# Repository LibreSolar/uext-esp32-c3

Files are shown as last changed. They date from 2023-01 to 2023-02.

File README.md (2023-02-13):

# WiFi/Bluetooth communication board based on ESP32-C3 for UEXT connector

 First boards tested, some issues might still be open.

Schematic: [PDF file](build/uext-esp32-c3.pdf)

Bill of Materials: [CSV file](build/uext-esp32-c3_bom.csv) or [interactive HTML BOM](https://libre.solar/uext-esp32-c3/build/uext-esp32-c3_ibom.html)

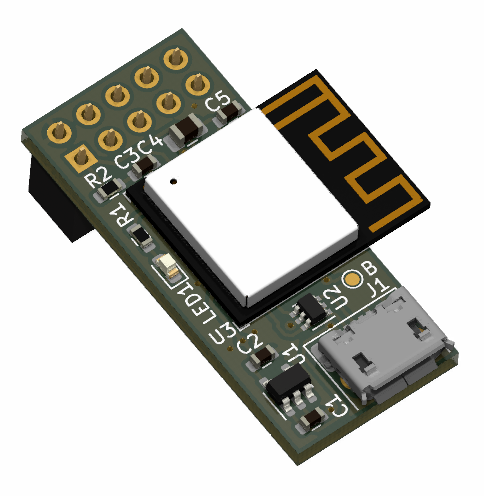
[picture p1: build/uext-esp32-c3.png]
UEXT ESP32 Module


## Features

- UEXT connector to communicate with host MCU via UART
- Flashing via built-in USB port
- Internal power supply for firmware upgrades

## Firmware

This board can be programmed with [Zephyr RTOS](https://docs.zephyrproject.org/latest/) or [ESP-IDF](https://docs.espressif.com/projects/esp-idf/en/latest/esp32c3/get-started/index.html).

## License

The hardware is licensed under the [CERN Open Hardware Licence Version 2 - Weakly Reciprocal](LICENCE).

Documentation is licensed under the [Creative Commons Attribution-ShareAlike 4.0 International (CC BY-SA 4.0) License](https://creativecommons.org/licenses/by-sa/4.0/).

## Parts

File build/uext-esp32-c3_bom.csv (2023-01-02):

Component | References | Value | Footprint | Description | Quantity Per PCB | Manufacturer | PartNumber | Remarks | DNM
1 | C5 | 100nF | C_0603_1608 |  | 1 | any |  | 50V, X7R
2 | C3 | 1uF | C_0603_1608 |  | 1 | any |  | 10V, X5R
3 | C1 C2 | 2.2u | C_0603_1608 |  | 2 | any |  | 10V, X5R
4 | C4 | 10uF | C_0805_2012 |  | 1 | any |  | 10V, X5R
5 | J2 | UEXT | PinSocket_2x05_P2.54mm_Vertical | Olimex UEXT connector (2x5 box header) | 1 | any
6 | J1 | USB_B_Micro | USB_Micro-B_10103594-0001LF | USB Micro Type B connector | 1 | Amphenol FCI | 10103594-0001LF
7 | LED1 | LED | LED_0603_1608Metric | Light emitting diode | 1 | any | red
8 | R1 | 1k | R_0603_1608 | Resistor | 1 | any
9 | R2 | 10k | R_0603_1608 | Resistor | 1 | any
10 | U1 | AP2210-3.3 | SOT-23-5 | 300mA low dropout linear regulator, shutdown pin, 1.5V fixed positive output, SOT-23-5 package | 1 | Diodes Inc. | AP2210K-3.3TRG1 | Alternative: MIC5225
11 | U3 | ESP32-C3-MINI-1 | ESP32-C3-MINI-1 | ESP32-C3-MINI-1 is a general-purpose Wi-Fi and Bluetooth LE module. This module features a rich set of peripherals and a small size, which makes it an ideal choice for smart home, industrial automation, health care, consumer electronics, etc | 1 | Espressif | ESP32-C3-MINI-1-N4
12 | U2 | NUP4202 | SOT-363_SC-70-6 | Transient voltage suppressor designed to protect high speed data lines from ESD, EFT, and lightning | 1 | On Semi | NUP4202W1T2G | Alternatives: Würth 82400274, Diodes D1213A-04S | Würth 82400274

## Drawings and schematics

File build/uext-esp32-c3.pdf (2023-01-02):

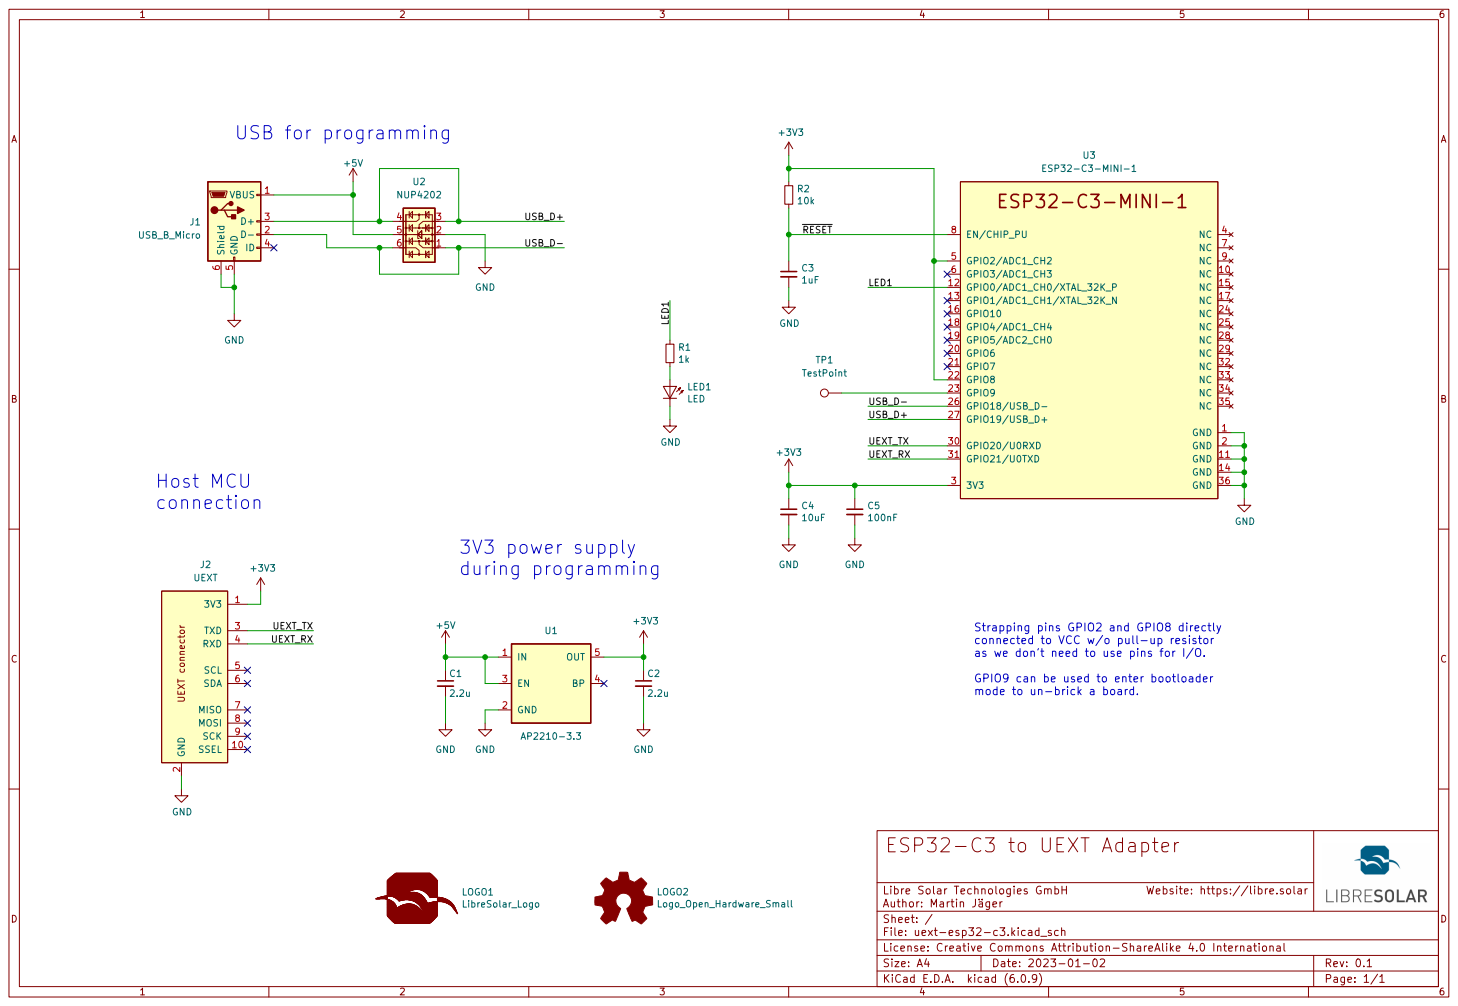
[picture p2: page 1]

GPIO9 can be used to enter bootloader mode to un-brick a board. Host MCU
connection
J2 UEXT GND

2 TXD 3 SCL 5 SDA 6 MISO 7 MOSI 8 SCK 9

Strapping pins GPIO2 and GPIO8 directly
connected to VCC w/o pull-up resistor
as we don't need to use pins for I/O.

þÿAuthor: Martin Jäger License: Creative Commons Attribution-ShareAlike 4.0 International

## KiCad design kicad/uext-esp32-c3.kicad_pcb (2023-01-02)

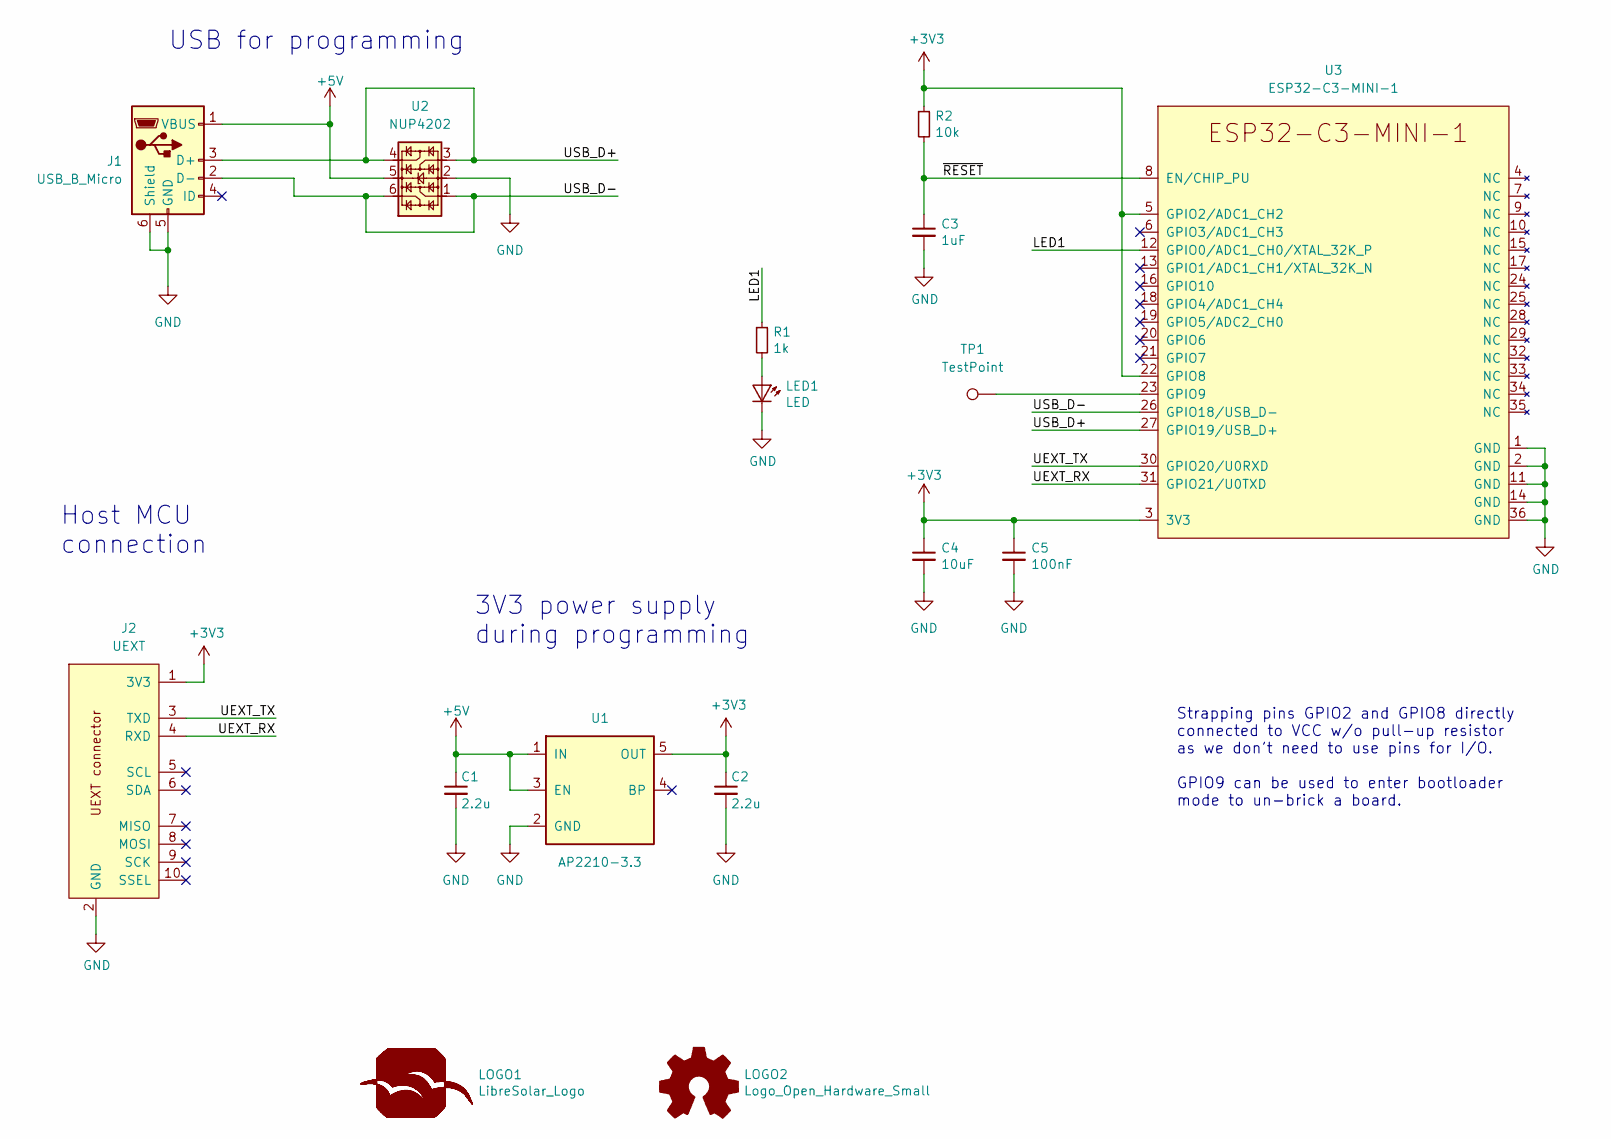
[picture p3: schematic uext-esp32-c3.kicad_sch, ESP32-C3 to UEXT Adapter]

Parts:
C1, C2: 2.2u; C_0603_1608
C3: 1uF; C_0603_1608
C4: 10uF; C_0805_2012
C5: 100nF; C_0603_1608
J1: USB_B_Micro; USB_Micro-B_10103594-0001LF; PartNumber 10103594-0001LF
J2: UEXT; PinSocket_2x05_P2.54mm_Vertical
LED1: LED; LED_0603_1608Metric; PartNumber red
LOGO1: LibreSolar_Logo; LIBRESOLAR_LOGO
LOGO2: Logo_Open_Hardware_Small; OSHW-Logo_5.7x6mm_SilkScreen
R1: 1k; R_0603_1608
R2: 10k; R_0603_1608
TP1: TestPoint; TestPoint_Pad_D1.0mm
U1: AP2210-3.3; SOT-23-5; PartNumber AP2210K-3.3TRG1
U2: NUP4202; SOT-363_SC-70-6; PartNumber NUP4202W1T2G
U3: ESP32-C3-MINI-1; PartNumber ESP32-C3-MINI-1-N4

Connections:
+3V3: C2.1, C4.1, C5.1, J2.1 (3V3), R2.1, U1.5 (OUT), U3.3 (3V3), U3.5 (GPIO2/ADC1_CH2), U3.22 (GPIO8)
+5V: C1.1, J1.1 (VBUS), U1.1 (IN), U1.3 (EN), U2.5
/LED1: R1.1, U3.12 (GPIO0/ADC1_CH0/XTAL_32K_P)
/UEXT_RX: J2.4 (RXD), U3.31 (GPIO21/U0TXD)
/UEXT_TX: J2.3 (TXD), U3.30 (GPIO20/U0RXD)
/USB_D+: J1.3 (D+), U2.3, U2.4, U3.27 (GPIO19/USB_D+)
/USB_D-: J1.2 (D-), U2.1, U2.6, U3.26 (GPIO18/USB_D-)
/~RESET: C3.1, R2.2, U3.8 (EN/CHIP_PU)
GND: C1.2, C2.2, C3.2, C4.2, C5.2, J1.5 (GND), J1.6 (Shield), J2.2 (GND), LED1.1 (K), U1.2 (GND), U2.2, U3.1 (GND), U3.2 (GND), U3.11 (GND), U3.14 (GND), U3.36 (GND)
unnamed: LED1.2 (A), R1.2
unnamed: TP1.1, U3.23 (GPIO9)

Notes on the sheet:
3V3 power supply during programming
Host MCU connection
USB for programming
Strapping pins GPIO2 and GPIO8 directly connected to VCC w/o pull-up resistor as we don't need to use pins for I/O. GPIO9 can be used to enter bootloader mode to un-brick a board.

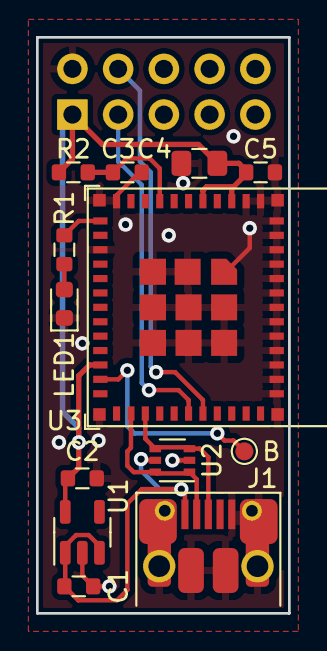
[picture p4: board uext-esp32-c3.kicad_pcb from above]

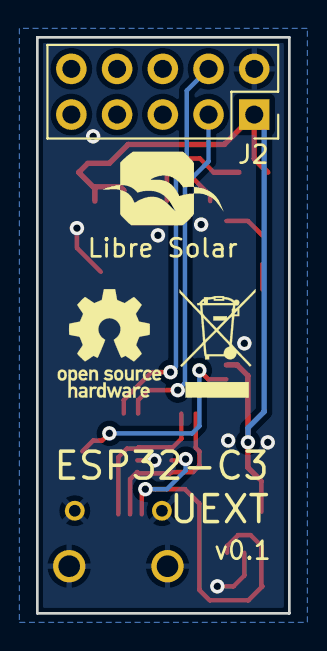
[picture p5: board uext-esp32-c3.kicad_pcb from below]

Board: 2 copper layers, 14.0 x 32.0 mm, 16 parts (3 on the bottom side), 11 nets.
